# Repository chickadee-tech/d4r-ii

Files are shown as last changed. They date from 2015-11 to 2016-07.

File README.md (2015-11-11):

# Chickadee Tech D4R-II Cradle Polystack Mod #
This mod connects a FrSky D4R-II to the base control board by cradling it.

## Documentation ##
See the [wiki](https://github.com/chickadee-tech/d4r-ii/wiki) for documentation.

## Polystack ##
This **mod** board is part of the Polystack platform for modular microcontrol systems. More information on the platform can be found at [polystack.org](http://polystack.org).

## Support ##
If you need support with a board you own or have development questions please email support@chickadee.tech or check [chickadee.tech/support](https://chickadee.tech/support) for other ways to get support.

## Contributing ##
Please note that this project is released with a [Contributor Code of Conduct](CODE_OF_CONDUCT.md). By participating in this project you agree to abide by its terms.

### Setup ###
Components and footprints for PCB parts are not included in this repository. Instead, checkout the [chickadee-tech/kicad-libs](https://github.com/chickadee-tech/kicad-libs) repository in the same directory that this repository is checked out in. All part definitions should be relative so that they will load correctly.

### Pull requests ###
For fixes please submit a pull request to the original repository. After the pull request is merged, check the [Chickadee Tech Active Contributor Discount (ACD)](https://chickadee.tech/active-contributor) to see if you are eligible for a discount code to use on your next purchase.

### Derivatives ###
If developing your own version of the D4R-II cradle board please remove all Chickadee Tech trademarks and follow the [CC-BY license](LICENSE). While not required, please consider open sourcing your modifications so others can learn from your improvements. If you do, then email support@chickadee.tech and we may choose to add your project to the ACD.

You may also license the Polystack logo for free by emailing support@chickadee.tech. We'll ask for your gerbers to ensure the design complies with specifications laid out [here](https://github.com/chickadee-tech/polystack/wiki) and provide written permission to use the trademark after compliance has been demonstrated.

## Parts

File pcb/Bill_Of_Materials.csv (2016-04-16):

v1 | symbol | size (imp) | max current | unit price | units per build | units in stock | order total | Manufacturer ID | source url | datasheet | datasheet2
80 pin header | PORT_IN1 |  |  | $1.35 | 1 | 1 | $1.35 | DF40C-80DP-0.4V(51) | http://www.digikey.com/product-detail/en/DF40C-80DP-0.4V(51)/H11632CT-ND/1969511 | N | http://www.hirose.co.jp/cataloge_hp/ed_DF40_20140305.pdf | Total Base Cost | #N/A
80 pin receptacle (4.0mm) | PORT_OUT1 |  |  | $2.67 | 1 | 8 | $2.67 | DF40HC(4.0)-80DS-0.4V(51) | http://www.digikey.com/product-detail/en/DF40HC(4.0)-80DS-0.4V(51)/H11919CT-ND/2530301 | N
AND/OR gate | PORT_ANDOR1 |  |  | $0.25 | 1 | 2 | $0.25 | SN74LVC1G0832DCKR | http://www.digikey.com/product-detail/en/SN74LVC1G0832DCKR/296-18754-1-ND/863884 |  | http://www.ti.com/lit/ds/symlink/sn74lvc1g0832.pdf
multifunction gate | PORT_XOR1, PORT_INV1 |  |  | $0.14 | 2 | 6 | $0.28 | SN74LVC1G58DCKR | http://www.digikey.com/product-detail/en/SN74LVC1G58DCKR/296-15577-1-ND/571153 |  | http://www.ti.com/lit/ds/symlink/sn74lvc1g58.pdf
64kbit eeprom | PORT_IC1 |  |  | $0.61 | 1 | 2 | $0.61 | AT24CS64-MAHM-T | http://www.digikey.com/product-detail/en/AT24CS64-MAHM-T/AT24CS64-MAHM-TCT-ND/4292118 | N | http://www.atmel.com/images/atmel-8870-seeprom-at24cs64-datasheet.pdf
R 10k | PORT_R1, R1 |  |  | $0.01 | 2 | 979 | $0.02 | RC0603FR-0710KL | http://www.digikey.com/product-detail/en/RC0603FR-0710KL/311-10.0KHRCT-ND/729827 | MF-RES-0603-10K
C 0.1uF | PORT_C1 |  |  | $0.02 | 1 | 400 | $0.02 | C0603C104K4RACTU | http://www.digikey.com/product-detail/en/C0603C104K4RACTU/399-1096-1-ND/411371 | MF-CAP-0603-0.1uF
#N/A | PCB |  |  | #N/A | 1 | #N/A | #N/A | CKD-D4R-II-V3 | #N/A | #N/A | #N/A
1x6 straight | P1, P1 |  |  | $0.30 | 2 | 3 | $0.60 | 22-28-4060 |  | N
n-channel mosfet | Q1, Q2 |  |  | $0.09 | 2 | 59 | $0.19 | BSS138 | http://www.digikey.com/product-detail/en/BSS138/BSS138CT-ND/244294 | MF-DSC-SOT233-BSS138 | https://www.fairchildsemi.com/datasheets/BS/BSS138.pdf
C 10uF X5R | C1 |  |  | $0.24 | 1 | 80 | $0.24 | C3216X5R1C106M160AA | http://www.digikey.com/product-detail/en/C3216X5R1C106M160AA/445-1426-1-ND/569092 | MF-CAP-1206-10uF | http://product.tdk.com/en/catalog/datasheets/mlcc_commercial_general_en.pdf
1x2 right angle tin straight | Off Board |  |  | $0.21 | 1 | 4 | $0.21 | 22-28-8020 | http://www.digikey.com/product-search/en?keywords=22-28-8020 | N
1x12 straight | Off Board |  |  | $0.58 | 1 | 0 | $0.58 | 22-28-4122 |  | N
4mm Spacer | Off Board |  |  | $0.04 | 5 | 78 | $0.19 | 908-4MM | http://www.mouser.com/ProductDetail/Bivar/908-4MM/ | N | http://www.bivar.com/Portals/0/Products/d.ashx?f=/Portals/0/products/9XX-XXX.pdf

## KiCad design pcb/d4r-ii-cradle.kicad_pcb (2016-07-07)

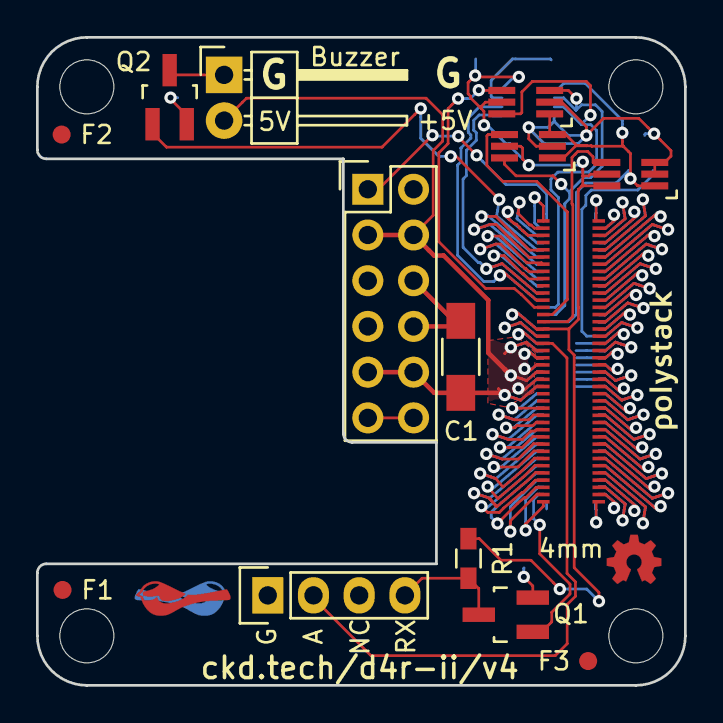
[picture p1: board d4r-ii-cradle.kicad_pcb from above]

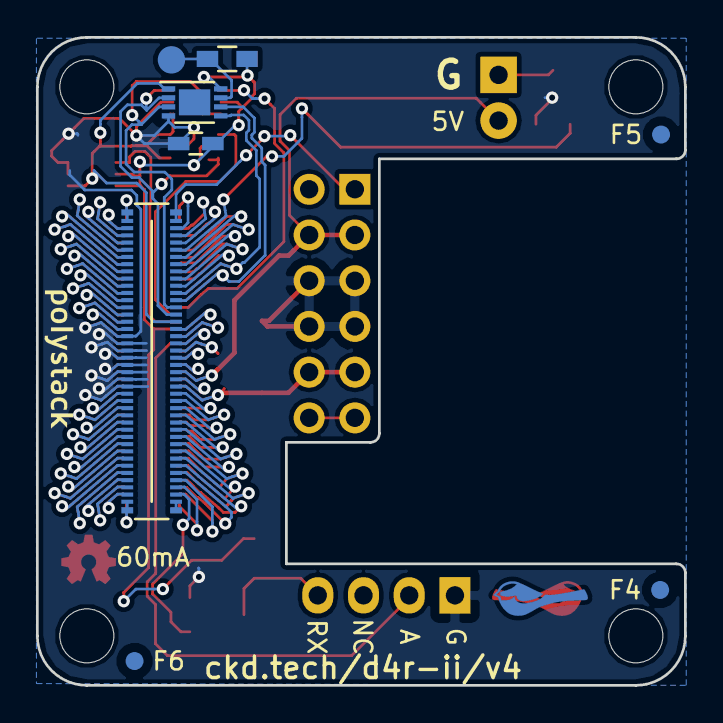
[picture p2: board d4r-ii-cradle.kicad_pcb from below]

Board: 2 copper layers, 36.0 x 36.0 mm, 24 parts (9 on the bottom side), 74 nets.

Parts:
C1: C; C_1206_HandSoldering
F1, F2, F3, F4, F5, F6: 1mm; Fiducial
P1: CONN_02X06; Pin_Header_Straight_2x06
P2: CONN_01X04; Pin_Header_Straight_1x04
P3: CONN_01X02; Pin_Header_Angled_1x02
PORT_ANDOR1: SN74LVC1G0832; SC-70-6_Handsoldering
PORT_C1: 0.1uF; C_0603_HandSoldering
PORT_IC1: AT24CS02-MAHM; DFN-8-1EP_3x2mm_Pitch0.5mm
PORT_IN1: CKD_SANDWICH; DF40-80pin-Header
PORT_INV1: SN74LVC1G58; SC-70-6_Handsoldering
PORT_OUT1: CKD_SANDWICH; DF40-3-4mm-80pin-Receptacle
PORT_P1: CONN_01X01; Measurement_Point_Round-SMD-Pad_Small
PORT_R1: 10k; R_0603_HandSoldering
PORT_XOR1: SN74LVC1G58; SC-70-6_Handsoldering
Q1, Q2: Q_NMOS_GSD; SOT-23_Handsoldering
R1: 10k; R_0603_HandSoldering
svg2mod, svg2mod#2: G***; polystack-bold-0.4

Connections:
+3V3: PORT_ANDOR1.5, PORT_C1.1, PORT_IC1.8, PORT_IN1.16, PORT_INV1.5, PORT_INV1.6, PORT_OUT1.16, PORT_R1.2, PORT_XOR1.5, R1.1
+5V: C1.1, P1.3, P1.4, P1.9, P1.10, P3.2, PORT_IN1.19, PORT_IN1.20, PORT_IN1.21, PORT_IN1.22, PORT_IN1.23, PORT_IN1.24, PORT_OUT1.19, PORT_OUT1.20, PORT_OUT1.21, PORT_OUT1.22, PORT_OUT1.23, PORT_OUT1.24
/ExpansionPort/3V3_0.3A_E: PORT_IN1.17, PORT_OUT1.17
/ExpansionPort/ADC1: PORT_IN1.49, PORT_OUT1.49
/ExpansionPort/ADC2: PORT_IN1.50, PORT_OUT1.50
/ExpansionPort/BATT_DIV: P2.2, PORT_IN1.18, PORT_OUT1.18
/ExpansionPort/GPIO1: PORT_IN1.5, Q2.1
/ExpansionPort/GPIO2: PORT_IN1.6, PORT_OUT1.5
/ExpansionPort/GPIO3: PORT_IN1.7, PORT_OUT1.6
/ExpansionPort/GPIO4: PORT_IN1.8, PORT_OUT1.7
/ExpansionPort/GPIO5: PORT_IN1.9, PORT_OUT1.8
/ExpansionPort/GPIO6: PORT_IN1.10, PORT_OUT1.9
/ExpansionPort/HEIGHT_1: PORT_ANDOR1.1, PORT_IC1.1, PORT_IN1.15, PORT_INV1.1, PORT_XOR1.1, PORT_XOR1.3
/ExpansionPort/HEIGHT_2: PORT_ANDOR1.3, PORT_IC1.2, PORT_IN1.14, PORT_XOR1.6
/ExpansionPort/HEIGHT_4: PORT_ANDOR1.6, PORT_IC1.3, PORT_IN1.13
/ExpansionPort/NEW_HEIGHT_1: PORT_INV1.4, PORT_OUT1.15
/ExpansionPort/NEW_HEIGHT_2: PORT_OUT1.14, PORT_XOR1.4
/ExpansionPort/NEW_HEIGHT_4: PORT_ANDOR1.4, PORT_OUT1.13
/ExpansionPort/SDMMC1_CK: PORT_IN1.55, PORT_OUT1.55
/ExpansionPort/SDMMC1_CMD: PORT_IN1.56, PORT_OUT1.56
/ExpansionPort/SDMMC1_D0: PORT_IN1.51, PORT_OUT1.51
/ExpansionPort/SDMMC1_D1: PORT_IN1.52, PORT_OUT1.52
/ExpansionPort/SDMMC1_D2: PORT_IN1.53, PORT_OUT1.53
/ExpansionPort/SDMMC1_D3: PORT_IN1.54, PORT_OUT1.54
/ExpansionPort/SPI1_MISO: PORT_IN1.79, PORT_OUT1.79
/ExpansionPort/SPI1_MOSI: PORT_IN1.80, PORT_OUT1.80
/ExpansionPort/SPI1_NSS: PORT_IN1.77, PORT_OUT1.77
/ExpansionPort/SPI1_SCK: PORT_IN1.78, PORT_OUT1.78
/ExpansionPort/SPI2_MISO: PORT_IN1.75, PORT_OUT1.75
/ExpansionPort/SPI2_MOSI: PORT_IN1.76, PORT_OUT1.76
/ExpansionPort/SPI2_NSS: PORT_IN1.73, PORT_OUT1.73
/ExpansionPort/SPI2_SCK: PORT_IN1.74, PORT_OUT1.74
/ExpansionPort/SPI3_MISO: PORT_IN1.71, PORT_OUT1.71
/ExpansionPort/SPI3_MOSI: PORT_IN1.72, PORT_OUT1.72
/ExpansionPort/SPI3_NSS: PORT_IN1.69, PORT_OUT1.69
/ExpansionPort/SPI3_SCK: PORT_IN1.70, PORT_OUT1.70
/ExpansionPort/SPI4_MISO: PORT_IN1.67, PORT_OUT1.67
/ExpansionPort/SPI4_MOSI: PORT_IN1.68, PORT_OUT1.68
/ExpansionPort/SPI4_NSS: PORT_IN1.65, PORT_OUT1.65
/ExpansionPort/SPI4_SCK: PORT_IN1.66, PORT_OUT1.66
/ExpansionPort/TIM1: P1.1, PORT_IN1.1
/ExpansionPort/TIM2: PORT_IN1.2, PORT_OUT1.1
/ExpansionPort/TIM3: PORT_IN1.3, PORT_OUT1.2
/ExpansionPort/TIM4: PORT_IN1.4, PORT_OUT1.3
/ExpansionPort/TIMG1_CH1: PORT_IN1.41, PORT_OUT1.41
/ExpansionPort/TIMG1_CH2: PORT_IN1.42, PORT_OUT1.42
/ExpansionPort/TIMG1_CH3: PORT_IN1.43, PORT_OUT1.43
/ExpansionPort/TIMG1_CH4: PORT_IN1.44, PORT_OUT1.44
/ExpansionPort/TIMG2_CH1: PORT_IN1.45, PORT_OUT1.45
/ExpansionPort/TIMG2_CH2: PORT_IN1.46, PORT_OUT1.46
/ExpansionPort/TIMG2_CH3: PORT_IN1.47, PORT_OUT1.47
/ExpansionPort/TIMG2_CH4: PORT_IN1.48, PORT_OUT1.48
/ExpansionPort/UART1_TX: PORT_IN1.39, Q1.1
/ExpansionPort/UART2_RX: PORT_IN1.38, PORT_OUT1.40
/ExpansionPort/UART2_TX: PORT_IN1.37, PORT_OUT1.39
/ExpansionPort/UART3_RX: PORT_IN1.36, PORT_OUT1.38
/ExpansionPort/UART3_TX: PORT_IN1.35, PORT_OUT1.37
/ExpansionPort/UART4_RX: PORT_IN1.34, PORT_OUT1.36
/ExpansionPort/UART4_TX: PORT_IN1.33, PORT_OUT1.35
/ExpansionPort/UART5_RX: PORT_IN1.32, PORT_OUT1.34
/ExpansionPort/UART5_TX: PORT_IN1.31, PORT_OUT1.33
/ExpansionPort/UART6_RX: PORT_IN1.30, PORT_OUT1.32
/ExpansionPort/UART6_TX: PORT_IN1.29, PORT_OUT1.31
/ExpansionPort/UART7_RX: PORT_IN1.28, PORT_OUT1.30
/ExpansionPort/UART7_TX: PORT_IN1.27, PORT_OUT1.29
/ExpansionPort/UART8_RX: PORT_IN1.26, PORT_OUT1.28
/ExpansionPort/UART8_TX: PORT_IN1.25, PORT_OUT1.27
/ExpansionPort/i2c_SCL: PORT_IC1.6, PORT_IN1.12, PORT_OUT1.12
/ExpansionPort/i2c_SDA: PORT_IC1.5, PORT_IN1.11, PORT_OUT1.11
/nTELEM: P2.4, Q1.3, R1.2
GNDPWR: C1.2, P1.5, P1.6, P1.7, P1.8, P2.1, PORT_ANDOR1.2, PORT_C1.2, PORT_IC1.4, PORT_IN1.57, PORT_IN1.58, PORT_IN1.59, PORT_IN1.60, PORT_IN1.61, PORT_IN1.62, PORT_IN1.63, PORT_IN1.64, PORT_INV1.2, PORT_INV1.3, PORT_OUT1.57, PORT_OUT1.58, PORT_OUT1.59, PORT_OUT1.60, PORT_OUT1.61, PORT_OUT1.62, PORT_OUT1.63, PORT_OUT1.64, PORT_XOR1.2, Q1.2, Q2.2
unnamed: P1.11, P1.12
unnamed: P3.1, Q2.3
unnamed: PORT_IC1.7, PORT_P1.1, PORT_R1.1

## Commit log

2015-11-11 Cradle for a D4R-II v1.
    [Bill_Of_Materials.csv, ExpansionPort.sch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]
2016-02-06 v2 of D4R-II cradle that adds telemetry inverter and buzzer
    [ExpansionPort.sch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]
2016-03-05 D4R-II v2 which adds telemetry inverter and buzzer pins.
    Also adds holes for the rest of the telemetry connector.
    [Bill_Of_Materials.csv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]
2016-04-13 Rebrand everything to Polystack and increment versions.
    [d4r-ii-cradle.kicad_pcb]
2016-04-16 Final gerbers for test manufacturing run.
    [Bill_Of_Materials.csv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]
2016-06-07 Update polystack logo to bold variant and bump version number.
    [d4r-ii-cradle.kicad_pcb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]
2016-07-07 Add license information to many files. PCB design files are CC-BY and code is MIT license.
    [ExpansionPort.sch, d4r-ii-cradle.kicad_pcb, d4r-ii-cradle.sch]
2016-07-07 Convert to relative component and footprint paths.
    [ExpansionPort.sch, d4r-ii-cradle.sch]

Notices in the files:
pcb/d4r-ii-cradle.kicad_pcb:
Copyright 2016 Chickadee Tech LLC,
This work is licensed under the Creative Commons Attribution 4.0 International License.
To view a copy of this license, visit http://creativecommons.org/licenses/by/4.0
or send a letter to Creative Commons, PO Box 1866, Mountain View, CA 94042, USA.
